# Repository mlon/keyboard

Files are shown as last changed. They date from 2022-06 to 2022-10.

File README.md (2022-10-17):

# Keyboard

A custom 37 keys MIDI keyboard

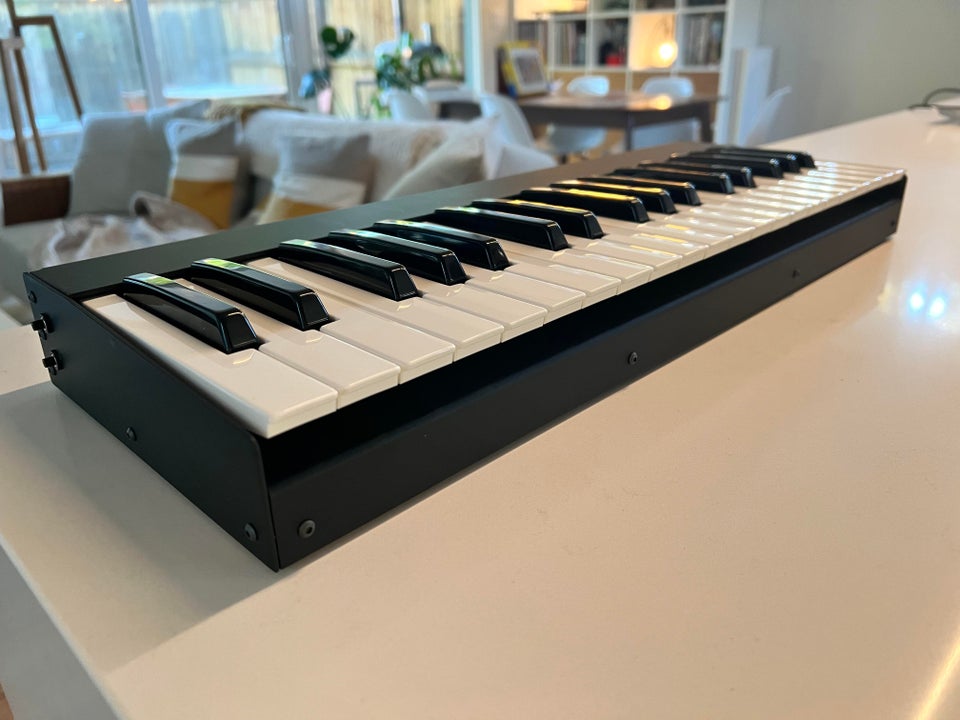
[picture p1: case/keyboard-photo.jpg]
Keyboard Photo

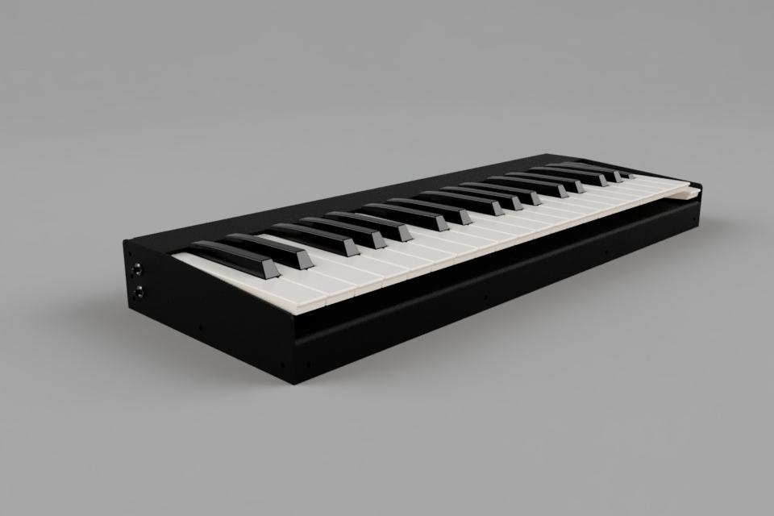
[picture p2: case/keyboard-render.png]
Keyboard Rendering


- [case](./case/) contains a step file of the keyboard assembly, and exports of each panel to be cut and bent.
- [pcb](./pcb/) contains the Kicad project for the matrix scanner.
- [src](./src/) contains the firmware for the matrix scanner.

## License

Code: MIT License

Hardware: cc-by-sa-4.0

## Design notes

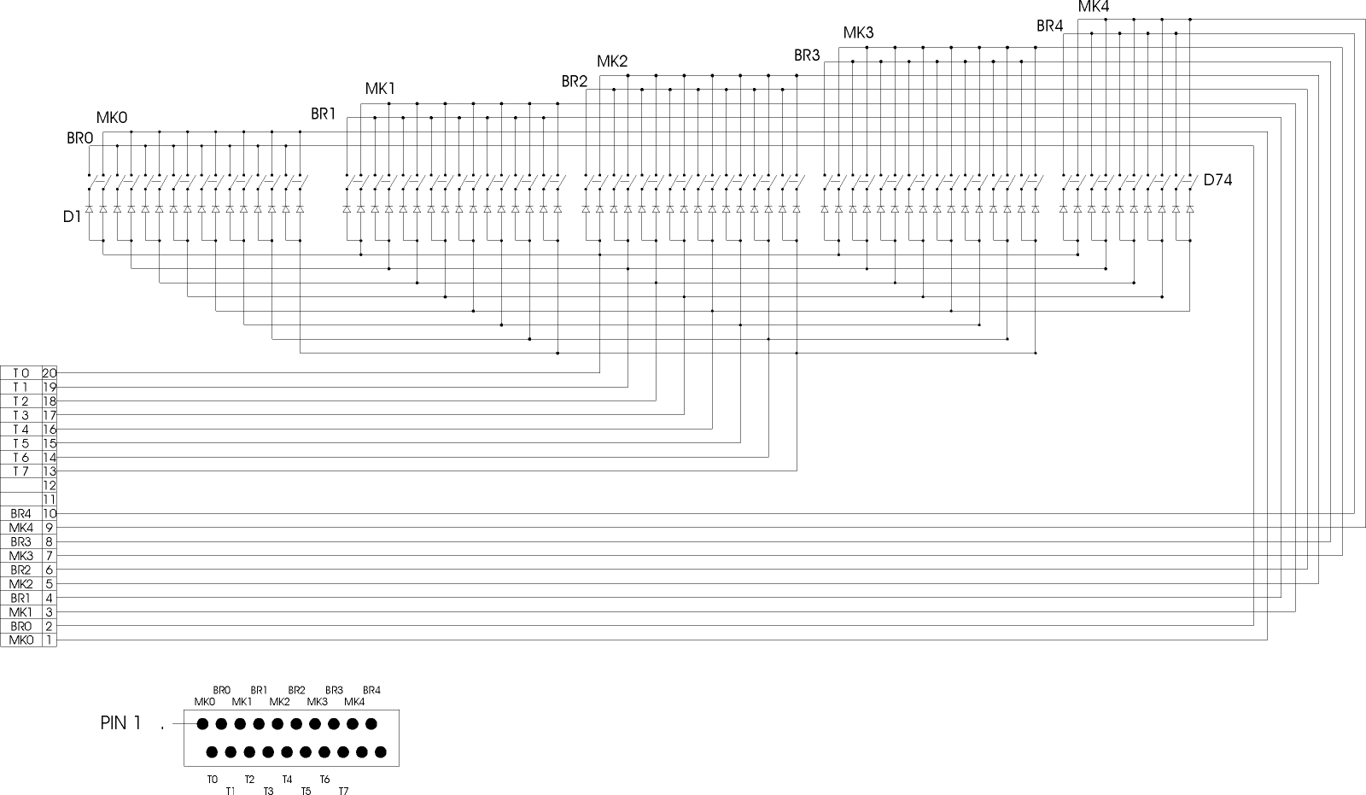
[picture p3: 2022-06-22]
datasheets/Matrix_37.gif

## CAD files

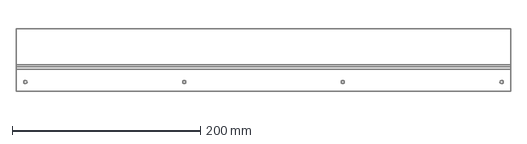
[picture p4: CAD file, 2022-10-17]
case/front.dxf
524.7 x 66.1 mm

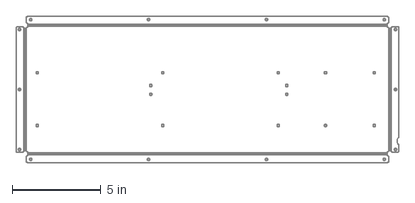
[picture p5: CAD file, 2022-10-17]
case/bottom.dxf
21.5 x 8.21 in

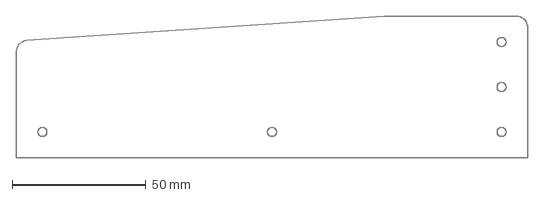
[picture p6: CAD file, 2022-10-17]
case/left.dxf
190.9 x 52.9 mm

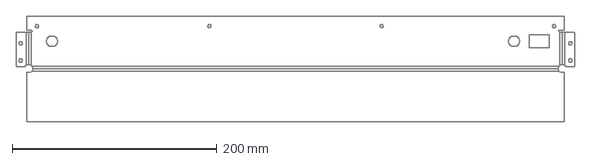
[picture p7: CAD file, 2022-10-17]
case/back.dxf
545.8 x 102.9 mm

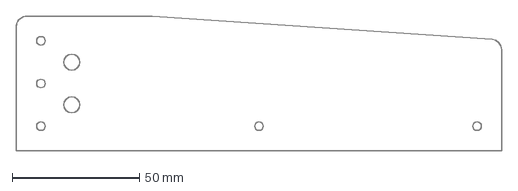
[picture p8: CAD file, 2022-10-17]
case/right.dxf
190.9 x 52.9 mm

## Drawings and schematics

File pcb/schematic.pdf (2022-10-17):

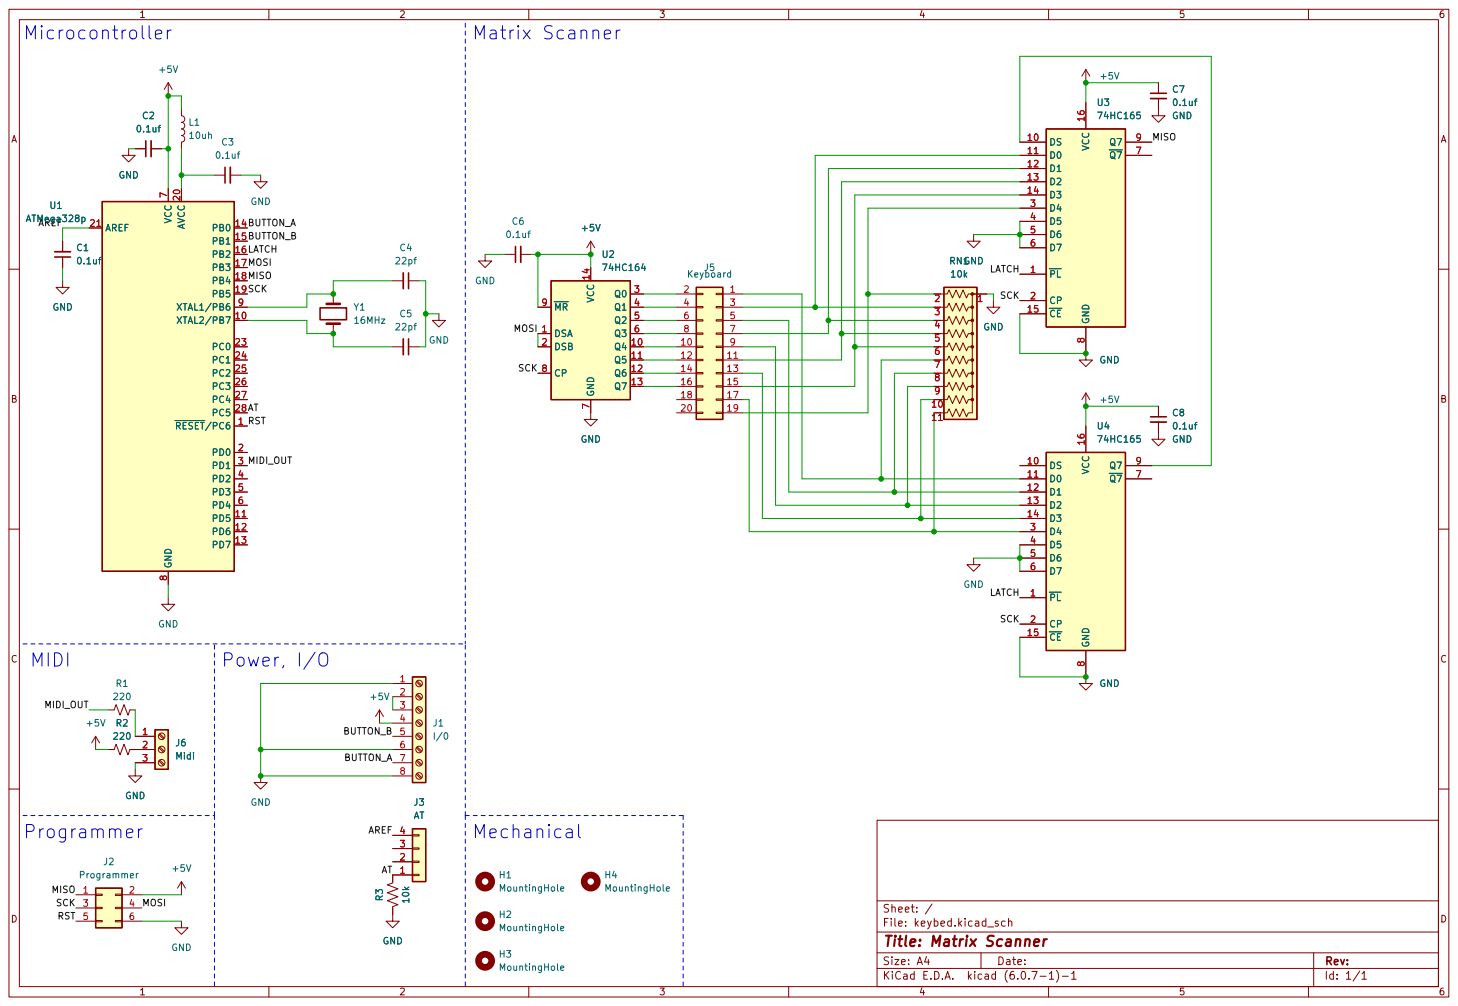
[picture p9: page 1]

12 | 11
14 | 13
16 | 15

File: keybed.kicad_sch Sheet: /
Id: 1/1 Title: Matrix Scanner

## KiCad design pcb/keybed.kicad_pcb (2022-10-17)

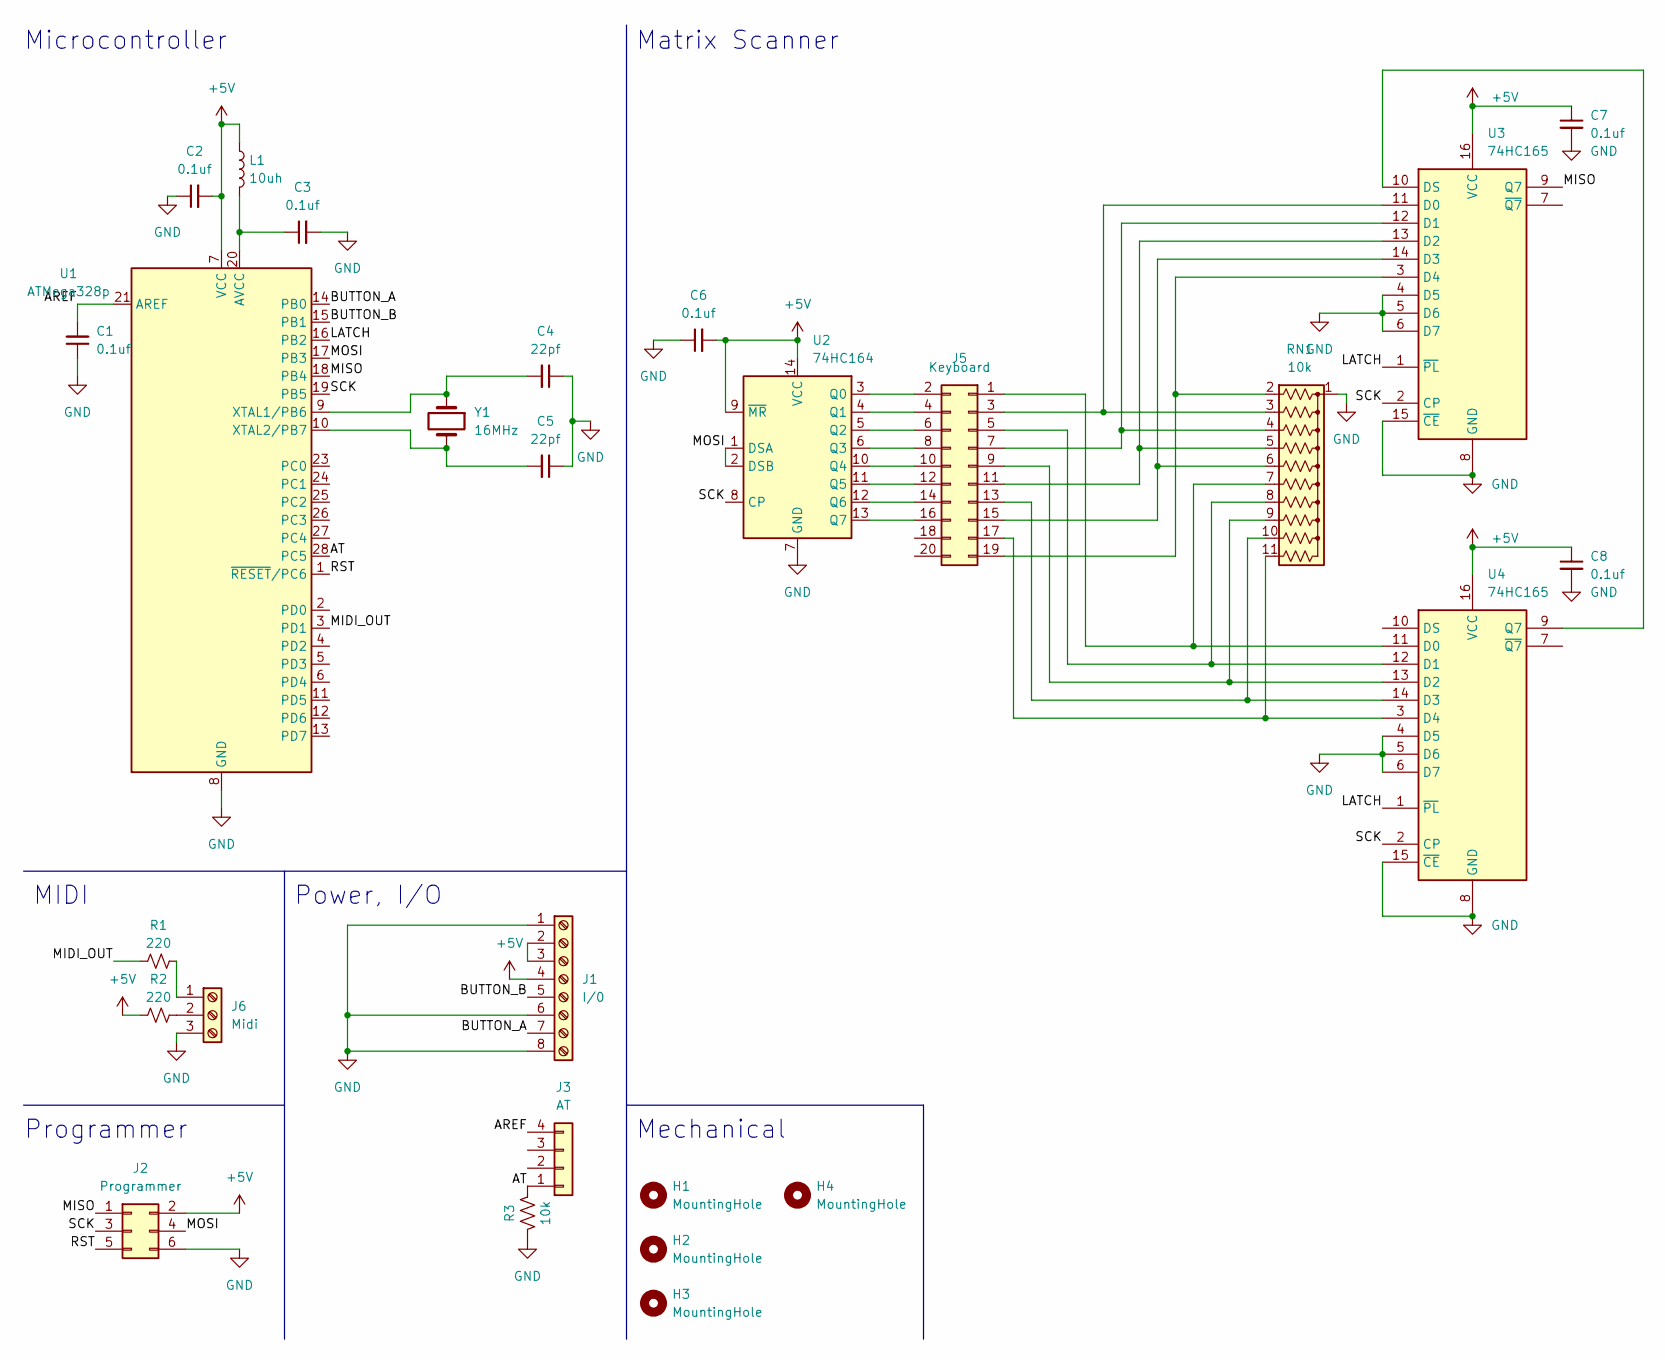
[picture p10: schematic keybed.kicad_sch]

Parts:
C1, C2, C3, C6, C7, C8: 0.1uf; C_Disc_D5.0mm_W2.5mm_P2.50mm
C4, C5: 22pf; C_Disc_D5.0mm_W2.5mm_P2.50mm
H1, H2, H3, H4: MountingHole; MountingHole_3.2mm_M3
J1: I/0; Altech_AK300_1x08_P5.00mm_45-Degree
J2: Programmer; PinHeader_2x03_P2.54mm_Vertical
J3: AT; PinHeader_1x04_P2.54mm_Horizontal
J5: Keyboard; TE_9-215079-0
J6: Midi; Altech_AK300_1x03_P5.00mm_45-Degree
L1: 10uh; 22R103C
R1, R2: 220; R_Axial_DIN0207_L6.3mm_D2.5mm_P7.62mm_Horizontal
R3: 10k; R_Axial_DIN0207_L6.3mm_D2.5mm_P7.62mm_Horizontal
RN1: 10k; R_Array_SIP11
U1: ATMega328p; DIP-28_W7.62mm_Socket
U2: 74HC164; DIP-14_W7.62mm_Socket
U3, U4: 74HC165; DIP-16_W7.62mm_Socket
Y1: 16MHz; Crystal_HC49-4H_Vertical

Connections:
+5V: C2.2, C6.2, C7.1, C8.1, J1.4, J2.2, L1.1, R2.1, U1.7 (VCC), U2.9 (~MR), U2.14 (VCC), U3.16 (VCC), U4.16 (VCC)
/AREF: C1.2, J3.4, U1.21 (AREF)
/AT: J3.1, R3.1, U1.28 (PC5)
/BUTTON_A: J1.7, U1.14 (PB0)
/BUTTON_B: J1.5, U1.15 (PB1)
/LATCH: U1.16 (PB2), U3.1 (~PL), U4.1 (~PL)
/MIDI_OUT: R1.1, U1.3 (PD1)
/MISO: J2.1, U1.18 (PB4), U3.9 (Q7)
/MOSI: J2.4, U1.17 (PB3), U2.1 (DSA), U2.2 (DSB)
/RST: J2.5, U1.1 (~RESET/PC6)
/SCK: J2.3, U1.19 (PB5), U2.8 (CP), U3.2 (CP), U4.2 (CP)
GND: C1.1, C2.1, C3.2, C4.1, C5.1, C6.1, C7.2, C8.2, J1.1, J1.6, J1.8, J2.6, J6.3, R3.2, RN1.1 (common), U1.8 (GND), U1.22 (GND), U2.7 (GND), U3.4 (D5), U3.5 (D6), U3.6 (D7), U3.8 (GND), U3.15 (~CE), U4.4 (D5), U4.5 (D6), U4.6 (D7), U4.8 (GND), U4.15 (~CE)
unnamed: C3.1, L1.2, U1.20 (AVCC)
unnamed: C4.2, U1.9 (XTAL1/PB6), Y1.1
unnamed: C5.2, U1.10 (XTAL2/PB7), Y1.2
unnamed: J1.2, J1.3
unnamed: J5.1, RN1.7 (R6), U4.11 (D0)
unnamed: J5.2, U2.3 (Q0)
unnamed: J5.3, RN1.3 (R2), U3.11 (D0)
unnamed: J5.4, U2.4 (Q1)
unnamed: J5.5, RN1.8 (R7), U4.12 (D1)
unnamed: J5.6, U2.5 (Q2)
unnamed: J5.7, RN1.4 (R3), U3.12 (D1)
unnamed: J5.8, U2.6 (Q3)
unnamed: J5.9, RN1.9 (R8), U4.13 (D2)
unnamed: J5.10, U2.10 (Q4)
unnamed: J5.11, RN1.5 (R4), U3.13 (D2)
unnamed: J5.12, U2.11 (Q5)
unnamed: J5.13, RN1.10 (R9), U4.14 (D3)
unnamed: J5.14, U2.12 (Q6)
unnamed: J5.15, RN1.6 (R5), U3.14 (D3)
unnamed: J5.16, U2.13 (Q7)
unnamed: J5.17, RN1.11 (R10), U4.3 (D4)
unnamed: J5.19, RN1.2 (R1), U3.3 (D4)
unnamed: J6.1, R1.2
unnamed: J6.2, R2.2
unnamed: U3.10 (DS), U4.9 (Q7)

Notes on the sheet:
Mechanical
Matrix Scanner
Microcontroller
Power, I/O
Programmer
MIDI

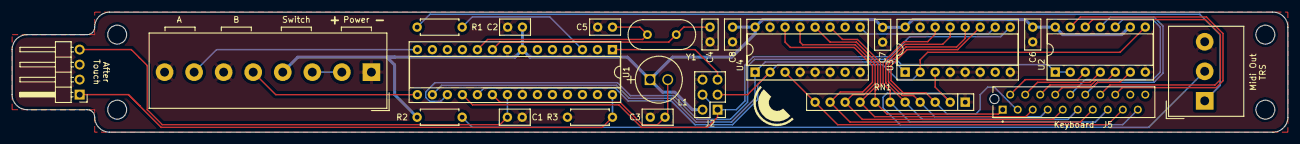
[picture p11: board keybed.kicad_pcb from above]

Board: 2 copper layers, 215.9 x 20.3 mm, 27 parts (0 on the bottom side), 37 nets.

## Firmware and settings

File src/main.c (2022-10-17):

#include <stdbool.h>
#include <stdlib.h>

#include <avr/interrupt.h>
#include <avr/io.h>
#include <math.h>
#include <util/atomic.h>
#include <util/delay.h>

#include "after_touch.h"
#include "matrix.h"
#include "midi.h"
#include "millis.h"
#include "transpose.h"

int main(void) {
  initMillis();
  initMidi();
  initMatrix();
  initTranspose();
  initAfterTouch();

  sei();

  while (true) {
    scanMatrix();
    processTranspose();
    processAfterTouch();
  }
}

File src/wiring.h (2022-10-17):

#pragma once

// PortB
#define BUTTON_A 0
#define BUTTON_B 1
#define LATCH 2
#define MOSI 3
#define MISO 4
#define SCK 5

// PortC
#define AFTER_TOUCH 5

// PortD
#define TX 1

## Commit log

2022-09-02 Use SPI for matrix scanning
2022-09-04 Working matrix scan and velocity
2022-09-05 Make velocity work
2022-10-17 Add support for transpose buttons
2022-10-17 Added schematic and files to build case
    [back.dxf, bottom.dxf, front.dxf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]

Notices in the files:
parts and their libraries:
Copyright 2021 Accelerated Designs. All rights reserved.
